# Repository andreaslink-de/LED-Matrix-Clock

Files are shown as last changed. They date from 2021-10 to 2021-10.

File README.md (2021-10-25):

# LED-Matrix-Clock

This [Link-Technologies.de](http://link-tech.de) project is about a simple ESP8266 driven clock.
Ok, another clock you ask, what is the purpose and what makes it special?

Well, as I am shortsighted and as I am sleeping without my glasses, I needed to have a clock on my nightstand, which is not too big, but big enough to be read without glasses in the night. It also has to be readable, but not too bright to disturb. It has to be exact and probably also slightly smart - and so I decided to create my own.

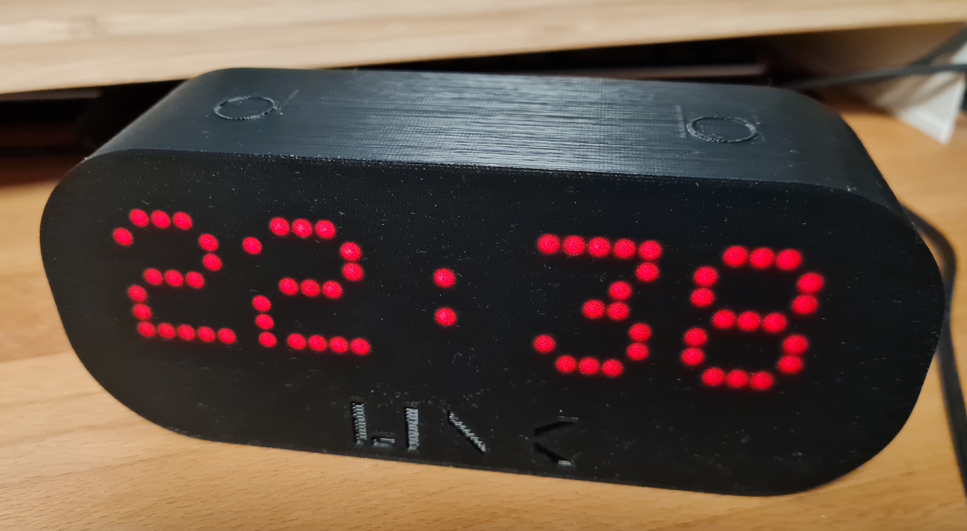
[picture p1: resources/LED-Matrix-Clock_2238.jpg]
LED-Matrix-Clock 22:38


This project describes a smart **LED-Matrix Clock**, which is readable without glasses in the night including some smart touch buttons and a temp/humidity sensor.

**This clock is able to...**

- show local time in big letters
- grab exact current time from internet
- change brightness
- be turned off aka fully dimmed (if being to bright)
- can be turned on again - permanently or only on demand
- connects to the (local) MQTT server
- has two touch buttons and posts the actions to the MQTT server aka broker
- subscribes to a topic of an outside temperature
- can show outside temperature on a touch
- has build in sensor to measure rooms local temperature and humidity (to provide via MQTT)
- can show sliding messages to transmit information (sent via MQTT)
- can show blinking alarm messages requiring attention (sent via MQTT)

## Technical Components

This clock is made of/implements...

- an ESP8266 (as WeMos D1 Mini) as core CPU
- four chained LED matrix (8x8) elements up to a visible 8x32 LED-Matrix
- a SHT21 for local temperature and humidity measurement
- two touch buttons (one dedicated and one multipurpose)
- Self designed black case (PLA) to dimm the brightness and hold it all together

## MQTT

After a successful start up and an active WiFi connection, the clock connects to the MQTT broker and sends some global health and info data.
The status is sent "retained" and can be used to determine, if the device is still there or has lost the connection to the broker (last will).

### Topics sent

Examples:

- 'zuhause/haus/schlafzimmer/iotdevice-clock/AndreasClockDevice/status': 'online'
- 'zuhause/haus/schlafzimmer/iotdevice-clock/AndreasClockDevice/clientid': 'IoTDevice-42AFFE'
- 'zuhause/haus/schlafzimmer/iotdevice-clock/AndreasClockDevice/devicename': 'iotdevice-clock'
- 'zuhause/haus/schlafzimmer/iotdevice-clock/AndreasClockDevice/version': '0.3'
- 'zuhause/haus/schlafzimmer/iotdevice-clock/AndreasClockDevice/ssid': ''IoT-Hausbus''
- 'zuhause/haus/schlafzimmer/iotdevice-clock/AndreasClockDevice/ip': '192.168.123.181'
- 'zuhause/haus/schlafzimmer/iotdevice-clock/AndreasClockDevice/mac': '50:02:91:42:AF:FE'
- 'zuhause/haus/schlafzimmer/iotdevice-clock/AndreasClockDevice/voltage': '3.089'
- 'zuhause/haus/schlafzimmer/iotdevice-clock/AndreasClockDevice/temperature': '20.1'
- 'zuhause/haus/schlafzimmer/iotdevice-clock/AndreasClockDevice/humidity': '41'

### Buttons

If the buttons are pressed, each pressing aka touching event is also sent via MQTT.
Some example events are:

- Button 1 clicked/touched:
  - 'zuhause/haus/schlafzimmer/iotdevice-clock/AndreasClockDevice/button1/touched': '1'
    - Typically to either show the outside temperature once
    - Or if display is turned off, show the time for some seconds
- Button 1 long pressed:
  - 'zuhause/haus/schlafzimmer/iotdevice-clock/AndreasClockDevice/button1/long': '1'
  - Turning LED Matrix off... good night!
  - If display is off, turn it on again
- Button 2 clicked/touched:
  - 'zuhause/haus/schlafzimmer/iotdevice-clock/AndreasClockDevice/button2/touched': '1'
  - Free event to implement/use in homeautomation system, e.g. turn on a night lamp
- Button 2 double clicked/touched:
  - 'zuhause/haus/schlafzimmer/iotdevice-clock/AndreasClockDevice/button2/doubletouched': '1'
  - Free event to implement/use in homeautomation system, e.g. turn on lights
- Button 2 long pressed:
  - 'zuhause/haus/schlafzimmer/iotdevice-clock/AndreasClockDevice/button2/long': '1'
  - Free event to implement/use in homeautomation system, e.g. open the blinds
  
 **Remind:**
 If Button 1 is pushed during boot, it will force the WiFi Manager to start up, so setup can be changed!

### Subscriptions and Commands

After reboot and successful connection to the MQTT broker the clock subscribes to the following topics (examples are according to initial setup via WiFi Manager).

**Subscribing to MQTT topics...**

- zuhause/garten/kinderhaus/aussen/temperatur
  - Last provided value is scrolled once when button 1 is pushed/touched
  - If no value is there, nothing happens
- zuhause/haus/schlafzimmer/iotdevice-clock/AndreasClockDevice/command/**reboot**
  - If value is 1, the clock is rebooted
- zuhause/haus/schlafzimmer/iotdevice-clock/AndreasClockDevice/command/**led**
  - If value is 1, the LED on the ESP8266 is turned on
  - If value is 0, the LED on the ESP8266 is turned off
  - If value is 2, the LED on the ESP8266 is toggled
  - Info: This function was implemented for testing and development purposes and does not give any real value.
- zuhause/haus/schlafzimmer/iotdevice-clock/AndreasClockDevice/command/**deletewificonfig**
  - Deletes the WiFi config and forces the WiFi Manager to kick in with the reboot
  - Triggers a reboot
- zuhause/haus/schlafzimmer/iotdevice-clock/AndreasClockDevice/command/**factoryreset**
  - Well, all is gone as the SPIFFS is fully wiped
- zuhause/haus/schlafzimmer/iotdevice-clock/AndreasClockDevice/command/**showmessage**
  - Scrolls the given text two times over the matrix
  - Can be used to transmit urgent short messages, e.g. by the home automation system
- zuhause/haus/schlafzimmer/iotdevice-clock/AndreasClockDevice/command/**showtext**
  - Shows a text with max. 5 chars flashing on highest brightness
  - Message is blinking a few times and then disappears again
  - Can be used to send e.g. 'ALARM' or any other <=5 char word
- zuhause/haus/schlafzimmer/iotdevice-clock/AndreasClockDevice/command/**setledmatrixstatus**
  - If value is 1, the LED matrix is turned on
  - If value is 0, the LED matrix is turned off
  - It can be used to automatically turn a display on and off triggered by a home automation system, such it is off in the nights (if someone is sensitive) or if no one is a home
  - Value is also set/influenced/changed when holding button 1
- zuhause/haus/schlafzimmer/iotdevice-clock/AndreasClockDevice/command/**setledmatrixbrightness**
  - Sets the brightness between 1 and 15

## Case

The case is 3D printed and the STLs are also available. Please find the main case [here](./case/Clock-MainCase_LED-Matrix-ESP8266_v1.stl). A first version of the back lid is added [here](./case/Clock-BackLid_LED-Matrix-ESP8266_v1.stl) as well, but I am still working on this one (as I forgot a holder and hole for the SHT21 sensor \*facepalm\*).

I have printed my case with common cheap black PLA on an Prusa MK3S and it is the first print shown on the pictures here. My print time was at around 5h to 6h.
The back lid is screwed on the case by melting some M3 nuts into the holes before. I like things screwed and no clips, which can break :-).

**Remind:** I recommand using plain _black PLA_ (or maybe PETG) to get the best effect of the LED matrix display shining though the front. I tried with white, but this was too bright for me.

### Outstanding todos

- Optimze the clips at the touch sensors --> Make them slightly thinner
- Slightly widen the USB Port hole
- Upload finished back lid and add corresponding pictures
- Add a sensor hole to the back lid

----------

## Pictures

See following some more pictures:

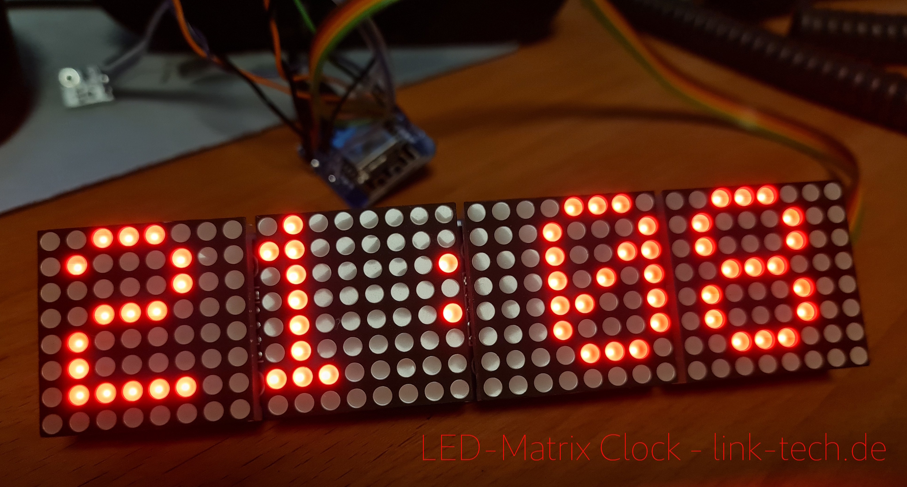
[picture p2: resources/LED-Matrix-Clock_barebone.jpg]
LED-Matrix-Clock 8x32 LED-Matrix 8x32


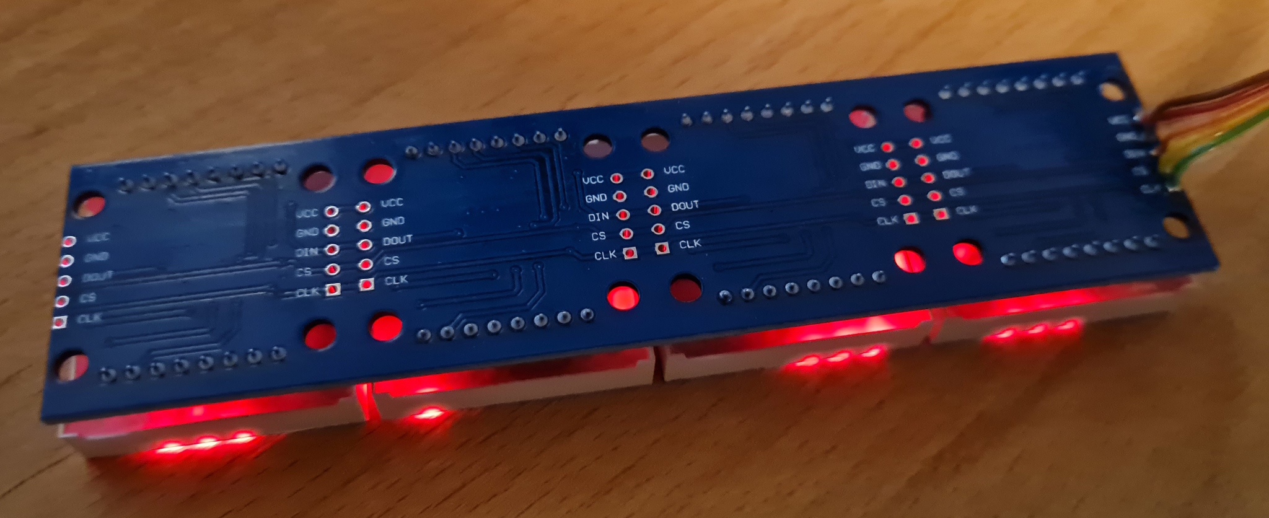
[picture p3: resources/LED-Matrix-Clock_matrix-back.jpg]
LED-Matrix-Clock LED-Matrix Back


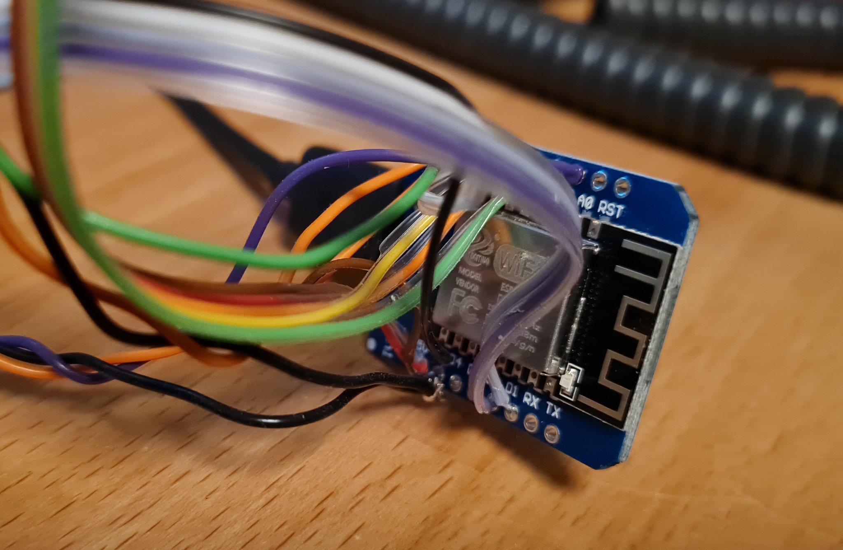
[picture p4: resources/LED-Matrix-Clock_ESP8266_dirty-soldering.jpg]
LED-Matrix-Clock soldered ES8266 LED-Matrix ESP8266 WeMos D1 Mini


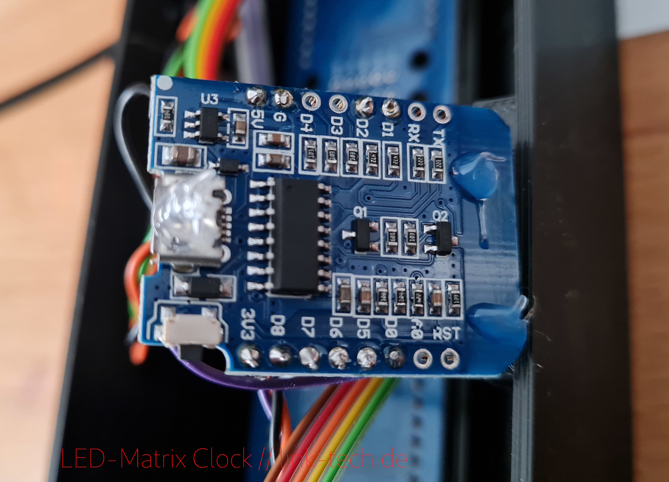
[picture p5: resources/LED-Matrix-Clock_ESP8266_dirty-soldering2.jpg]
LED-Matrix-Clock soldered ES8266 LED-Matrix ESP8266 WeMos D1 Mini


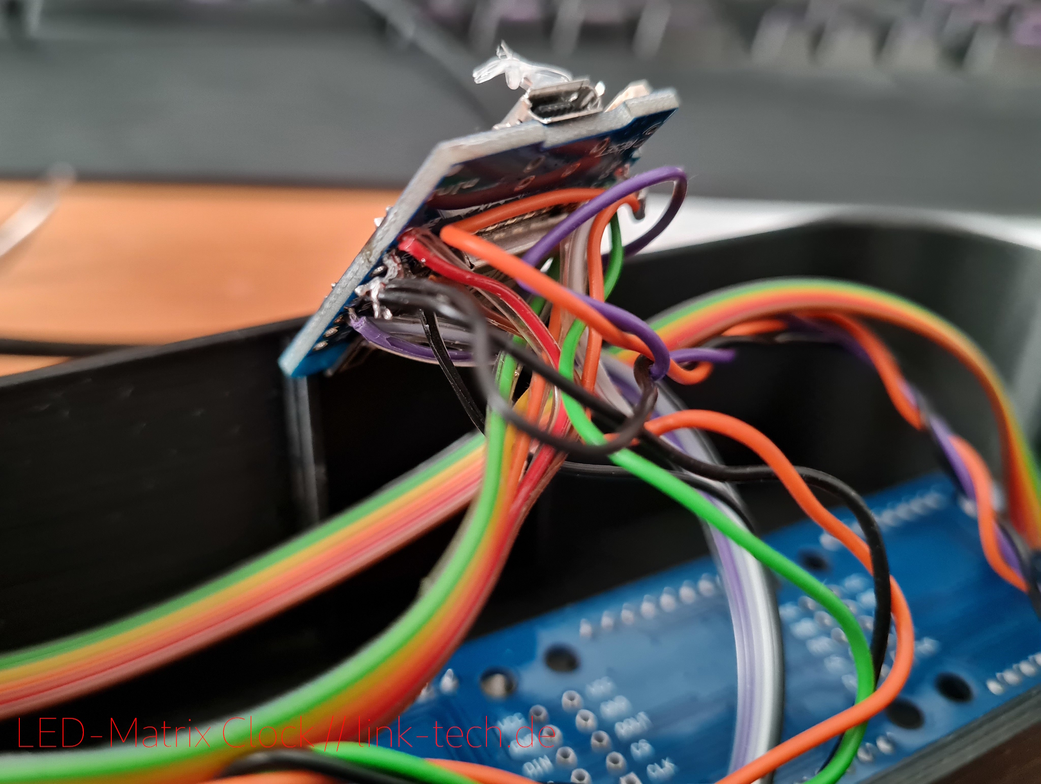
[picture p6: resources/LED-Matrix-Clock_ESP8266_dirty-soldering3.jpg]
LED-Matrix-Clock soldered ES8266 LED-Matrix ESP8266 WeMos D1 Mini


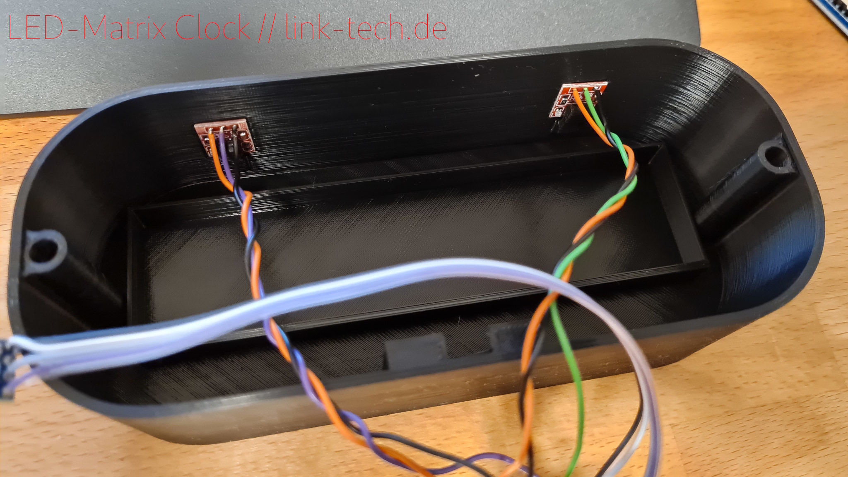
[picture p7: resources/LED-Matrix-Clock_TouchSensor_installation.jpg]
LED-Matrix-Clock Touch Sensor LED-Matrix Clock Touch Sensor Installation


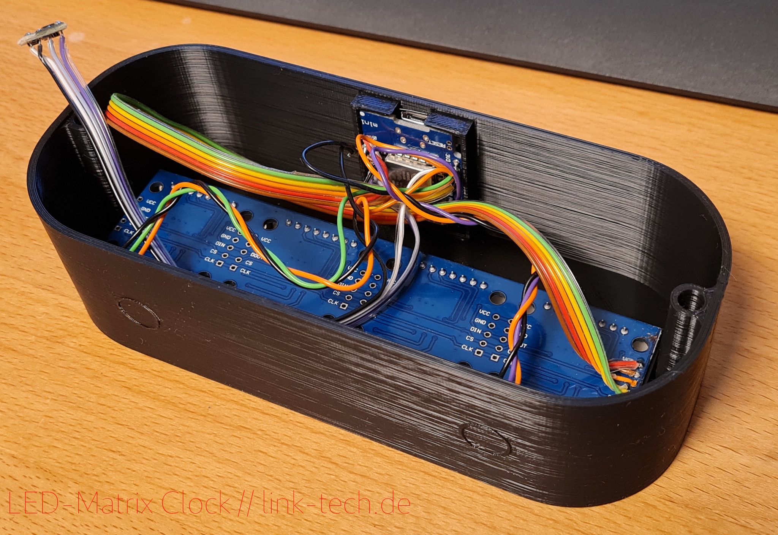
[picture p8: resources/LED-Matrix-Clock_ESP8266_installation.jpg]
LED-Matrix-Clock ESP8266 LED-Matrix Clock ESP8266 Installation


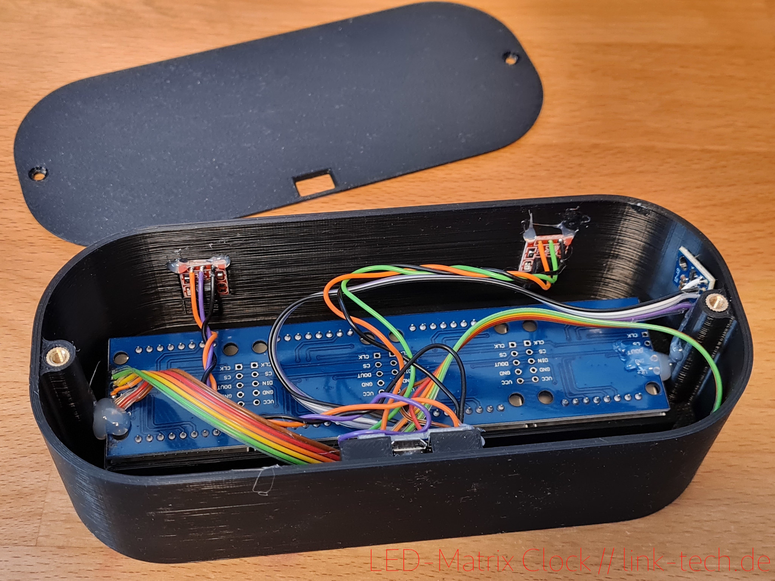
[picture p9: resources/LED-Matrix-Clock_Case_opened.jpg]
LED-Matrix-Clock Display, Touch Sensors, nuts LED-Matrix Clock Display and Touch Sensor installed, all hot glue fixed, M3 screw nuts


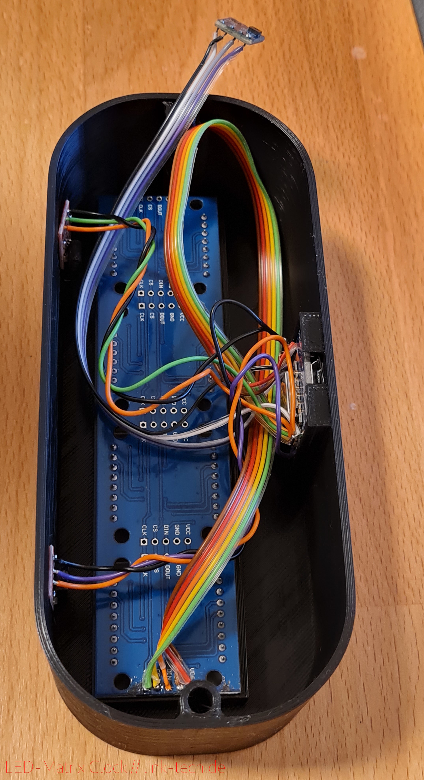
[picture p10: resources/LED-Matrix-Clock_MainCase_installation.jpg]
LED-Matrix-Clock Cableing LED-Matrix Clock Cableing


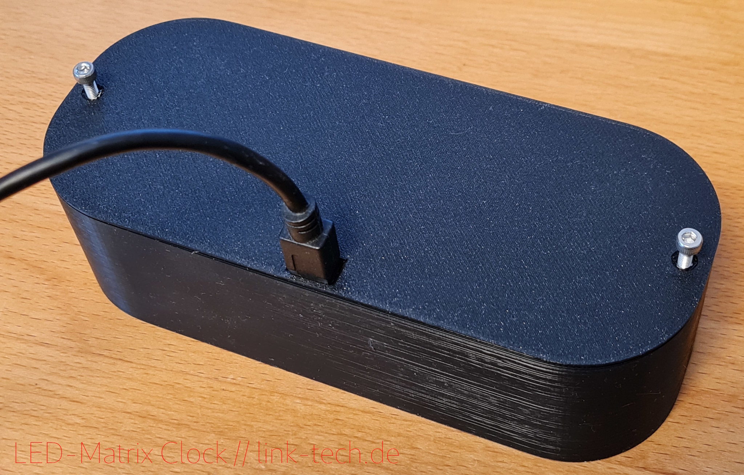
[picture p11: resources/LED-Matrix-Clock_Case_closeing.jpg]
LED-Matrix-Clock Closing LED-Matrix Clock Case M3 Screws Closing


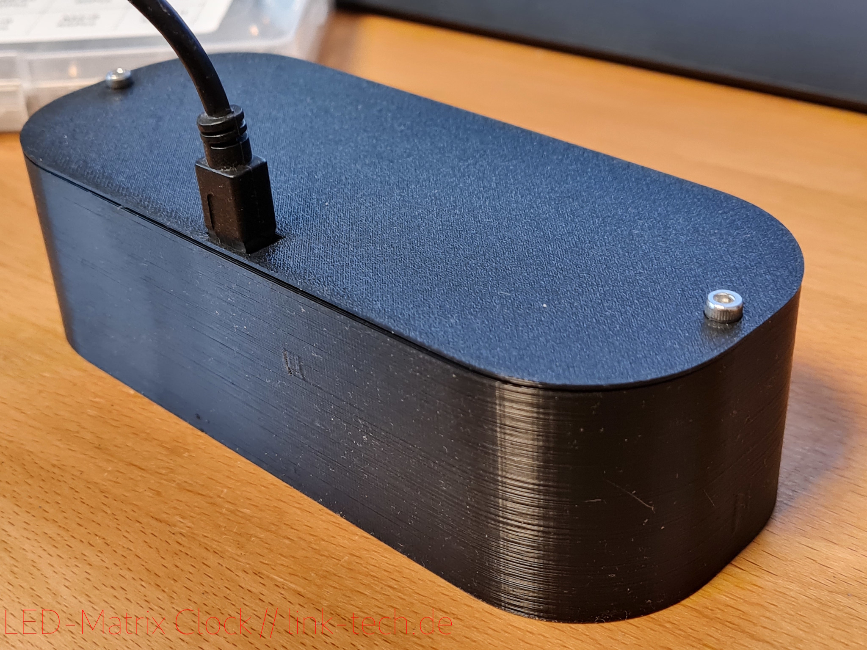
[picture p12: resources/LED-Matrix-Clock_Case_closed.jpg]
LED-Matrix-Clock Closed LED-Matrix Clock Case Closed


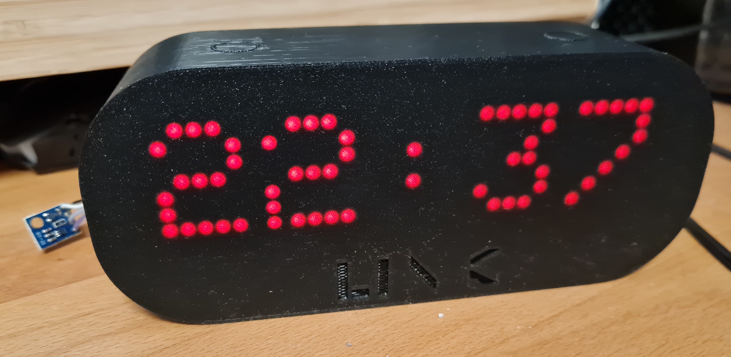
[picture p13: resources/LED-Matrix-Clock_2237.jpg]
LED-Matrix-Clock 22:37


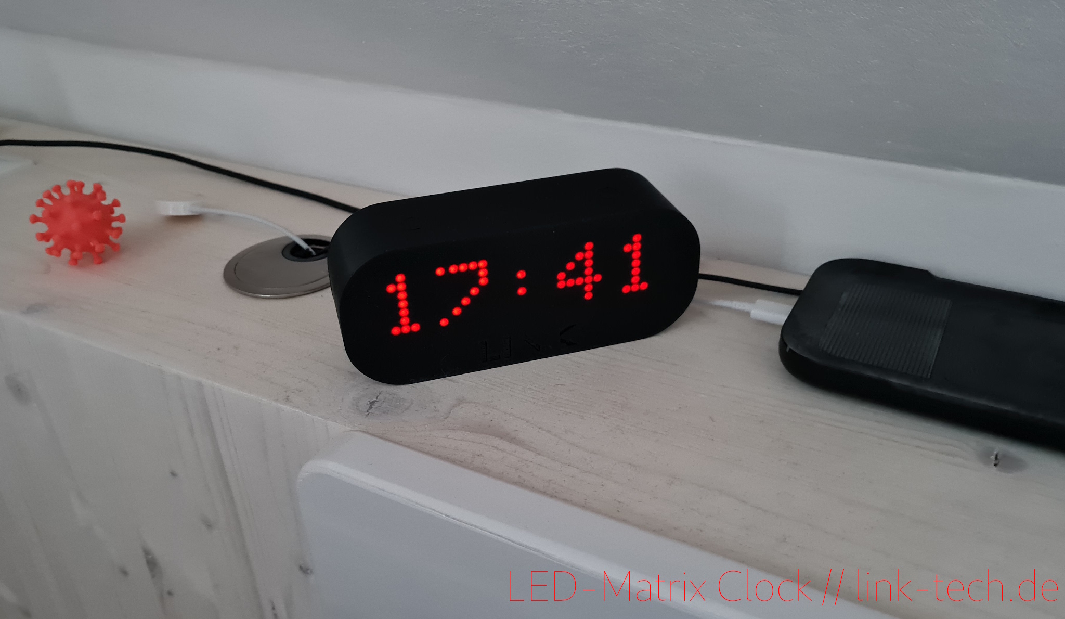
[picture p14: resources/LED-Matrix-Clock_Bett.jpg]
LED-Matrix-Clock Bett 17:41 LED-Matrix-Clock 17:41


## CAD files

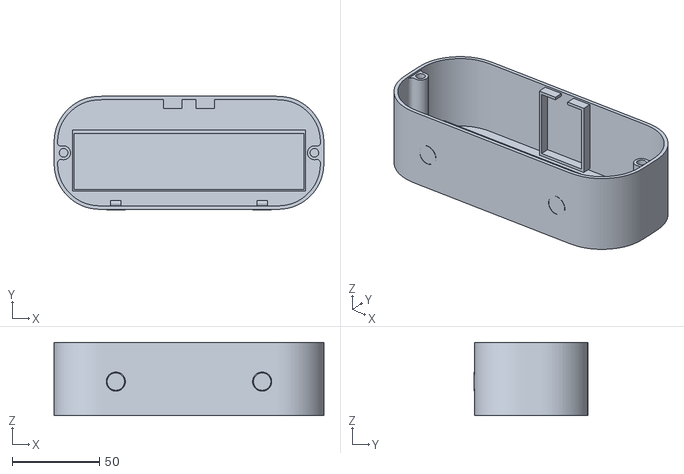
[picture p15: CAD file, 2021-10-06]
case/Clock-MainCase_LED-Matrix-ESP8266_v1.stl
155.0 x 65.2 x 42.0

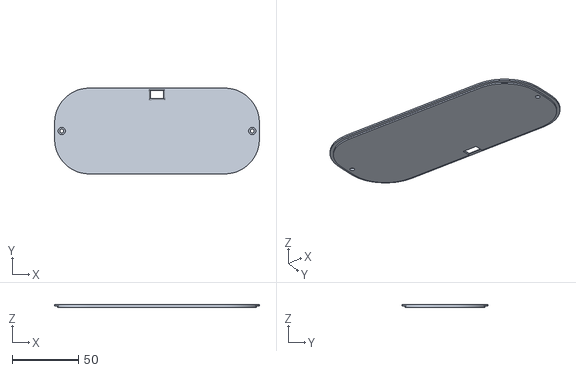
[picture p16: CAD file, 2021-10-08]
case/Clock-BackLid_LED-Matrix-ESP8266_v1.stl
155.0 x 65.0 x 2.00

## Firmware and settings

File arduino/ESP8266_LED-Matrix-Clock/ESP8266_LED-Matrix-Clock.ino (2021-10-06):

/*------------------------------------------------------------------------------------
 * ESP8266 - LED-Matrix Clock
 * 
 * Author:  Dipl.-Inform. (FH) Andreas Link
 * Date:    21.07.2021 Harrislee, Germany
 * Web:     Link-Technologies.de
 * License: GNU General Public License, Version 3
 * 
 * Usage:
 *   Boots, connects to WiFi or asks for WiFi access, connects to internet to get time from
 *   NTP server. Connects to MQTT server to send events if buttons are pushed/touched and to 
 *   subscribe to outside temperature.
 *   Firmwareupdates via OTA are possbile.
 *
 * Remind: 
 *   Consider to preset your "config.h" with relevant passswords for accessing the 
 *   WiFi Manager on first boot.
 ------------------------------------------------------------------------------------*/


#define DEBUG_OUTPUT      // Uncomment to enable serial IO debug messages
#define USE_MQTT          // Comment to deactivate MQTT (which is biggest part)
#define USE_NTP_TIME      // Comment to deactivate use of internet time to get correct local date and time
#define USE_SHT21         // Comment to deactivate use of SHT21 Temperature and Humidity sensor
//#define USE_BH1750        // Comment to deactivate BH1750 brightness integration <-- NOT YET FULLY IMPLEMENTED!



/* *********************************************** <<< DEBUG >>> ****************************************************/
////////////////////////
// Debug Serial Magic //
////////////////////////
#ifdef DEBUG_OUTPUT
  #define DEBUG(input)   { Serial.print(input); }
  #define DEBUGln(input) { Serial.println(input); }
#else
  #define DEBUG(input) ;
  #define DEBUGln(input) ;
#endif

/* *********************************************** >>> DEBUG <<< ****************************************************/


#define FW_VERSION "0.3"
#include "config.h"

#define MQTT_MAX_PACKET_SIZE 1024 // Remind: If you mess with this value and go too low, the code throws weird exceptions
#define BUTTON1   15              // GPIO15 aka D8
#define BUTTON2   16              // GPIO16 aka D0


#include <FS.h>                   // This needs to be first, or it all crashes and burns...
#include <ESP8266WiFi.h>          // https://github.com/esp8266/Arduino
#include <ESP8266mDNS.h>
#include <WiFiUdp.h>
#include <ArduinoOTA.h>
#include <DNSServer.h>
#include <ESP8266WebServer.h>
#include <WiFiManager.h>          // https://github.com/tzapu/WiFiManager
#include <ArduinoJson.h>          // https://github.com/bblanchon/ArduinoJson

#include <Adafruit_GFX.h>         // https://github.com/adafruit/Adafruit-GFX-Library
#include <Max72xxPanel.h>         // https://github.com/markruys/arduino-Max72xxPanel

#include <AceButton.h>
using namespace ace_button;

#ifdef USE_MQTT
  #include <PubSubClient.h>
#endif

#ifdef USE_NTP_TIME
  #include <NTPClient.h>
  #include <WiFiUdp.h>
  #include "RTClib.h"             //Makes DateTime calculations possible first
#endif

#ifdef USE_SHT21
  #include "SparkFunHTU21D.h"     // https://github.com/sparkfun/SparkFun_HTU21D_Breakout_Arduino_Library
#endif

#ifdef USE_BH1750
  #include <BH1750.h>             // https://github.com/claws/BH1750
#endif


//Read power via ADC
ADC_MODE(ADC_VCC);

/* *********************************************** <<< Config >>> ****************************************************/
// ----------------------------------------- MQTT ------------------------------------------ //
#ifdef USE_MQTT
  //MQTT-Topic/Data Max-Length
  #define MAX_TOPIC_LENGTH 100
  #define MAX_DATA_LENGTH 100
  
  //MQTT-Setup
  char mqttBaseTopic[MAX_TOPIC_LENGTH];
  char mqttButton1Topic[MAX_TOPIC_LENGTH];
  char mqttButton2Topic[MAX_TOPIC_LENGTH];
  char mqttLightTopic[MAX_TOPIC_LENGTH];
  char mqttTempTopic[MAX_TOPIC_LENGTH];
  char mqttHumidityTopic[MAX_TOPIC_LENGTH];
  
  //Dedicated subscribe topics
  //const char* mqttSubTopicOutTemp = "zuhause/garten/kinderhaus/aussen/temperatur";
    //const char* q = "abc";
    //const char*& c = q;
  
  const char* &mqttSubTopicOutTemp = outsideTemperatureMQTTtopic;
  const char* mqttSubTopicDate    = "system/date";
  const char* mqttSubTopicTime    = "system/time";
#endif


// ------------------------------------ WiFi-Manager --------------------------------------- //

//WiFiManager Vars:
bool shouldSaveConfigToFlash = false;  //Flag for saving data

//define your default values here, if there are different values in config.json, they are overwritten.
//length should be max size + 1
char flashIoTdeviceName[50];
char flashMQTTserver[40];
char flashMQTTport[6];
char flashMQTTbaseTopic[50];
char flashMQTTdeviceTopic[50];

//Vars:
float gESPVCC = 0.0;
String gIP = "not connected";
String gWiFiStatus = "not connected";

String curDate = "";
String curTime = "";
String gFormerTimeNow = "";
uint8_t gShowTimeOnce = false;

String gMacAdr = "00:00:00:00:00:00";
char gIdentifierAry[7];
String gIdentifier = "000000";
String gSSID = "";
uint8_t mqttConnectFailCounter = 0;
unsigned long lastDoSomethingEvent = 0;
unsigned long lastReconnectAttempt = 0;
boolean gForceWiFiManager = false;

//LED-Matrix ON/OFF status
uint8_t gLEDmatrixTurnedOn = true;
uint8_t gLEDmatrixWasTurnedOffBefore = false;

//Receive a message, and show it on the display vars
String gMessage = "";
uint8_t gNewMessageToShow = false;

//Blink Short Urgent Text vars
unsigned long lastShowTextTimeSlot = 0;
String gShortText = "";
uint8_t gNewTextToShow = false;
uint8_t gCurrentlyShowingText = false;
uint8_t gTextBlinkToggle = false;
unsigned long lastShowTextBlinkTimeSlot = 0;

//Show outside temp on display
String gOutsideTempStr = "N/A"; //Max char size: -00.00
unsigned long lastShowOutTempTimeSlot = 0;
uint8_t gNewOutTempToShow = false;
uint8_t gCurrentlyShowingOutsideTemp = false;


#ifdef USE_SHT21
  float gTempFl = 0.0;
  float gHumidityFl = 0;
  String gTempStr = "N/A";
  String gHumidityStr = "N/A";
  unsigned long lastTempHumiditySent = 0;

  //Defining SHT21 via SparkFun-Lib
  HTU21D sht21; // I²C-Address: 0x40
#endif

#ifdef USE_BH1750
  //Define BH1750 lightmeter
  BH1750 lightMeter(0x23);  // I²C-Address: 0x23

  unsigned long lastBrightnessSent = 0;
  uint16_t gLux = 0;
  String gLuxStr = "N/A";
#endif

#ifdef USE_NTP_TIME  
  WiFiUDP ntpUDP;

  // You can specify the time server pool and the offset (in seconds, can be
  // changed later with setTimeOffset() ). Additionaly you can specify the
  // update interval (in milliseconds, can be changed using setUpdateInterval() ).
  NTPClient timeClient(ntpUDP, "europe.pool.ntp.org", 3600, 60000);

  long gTargetDateLong = 0;
  boolean gDisplaySleeping = false;
#endif



//Define an ESP-WiFi-Client for MQTT-connection
WiFiClient espClient;

#ifdef USE_MQTT
  PubSubClient mqttClient(espClient);
#endif



/* *********************************************** Setup ****************************************************/
void setup()  
{
  //Basic assign of vars from config.h
  strncpy(flashIoTdeviceName, myFlashIoTdeviceName, 50);
  strncpy(flashMQTTserver, myFlashMQTTserver, 40);
  strncpy(flashMQTTport, myFlashMQTTport, 6);
  strncpy(flashMQTTbaseTopic, myFlashMQTTbaseTopic, 50);
  strncpy(flashMQTTdeviceTopic, myFlashMQTTdeviceTopic, 50);

  
  Serial.begin(115200);
  delay(100);

  DEBUGln();
  DEBUGln(F("------------------------------------------------------------"));
  DEBUG  (F("  Andreas Smart Clock v"));
  DEBUGln(FW_VERSION);
  DEBUG  (F("  ESP8266 Chip-ID: "));
  DEBUGln(ESP.getChipId());
  DEBUG  (F("  MAC Address: "));
  DEBUGln(WiFi.macAddress());
  DEBUGln();
  DEBUG  (F("  Sketch size (kB): "));
  DEBUG  (ESP.getSketchSize()/1000.0);
  DEBUG  (F(" ("));
  DEBUG  (ESP.getSketchSize());
  DEBUGln(F(" Byte)"));
  DEBUG  (F("  Free space (kB): "));
  DEBUG  (ESP.getFreeSketchSpace()/1000.0);
  DEBUG  (F(" ("));
  DEBUG  (ESP.getFreeSketchSpace());
  DEBUGln(F(" Byte)"));
  DEBUG  (F("  Free Mem/Heap (kB): "));
  DEBUG  (ESP.getFreeHeap()/1000.0);
  DEBUG  (F(" ("));
  DEBUG  (ESP.getFreeHeap());
  DEBUGln(F(" Byte)"));
  DEBUGln();
  DEBUGln(F("           Dipl.-Inform. (FH) Andreas Link"));  
  DEBUGln(F("               Release Build 07.2021"));
  DEBUGln(F("                www.andreaslink.de"));
  DEBUGln(F("             www.link-technologies.de"));
  DEBUGln(F("------------------------------------------------------------"));
  DEBUGln();

  // Prepare Debug-LED GPIO2 (TX1) for testing/measuring (IF NO SERIAL2 IS USED!)
  pinMode(LED_BUILTIN, OUTPUT); // Initialize digital pin LED_BUILTIN as an output.
  digitalWrite(LED_BUILTIN, HIGH); // Turn the LED off (HIGH = off, LOW = on)
  //pinMode(2, OUTPUT); // LED vorbereiten
  //digitalWrite(2, 1); // Turn LED off
  
  ledDoubleFlash();

  //Set unique MAC oriented device identifier
  gIdentifier = getUniqueDeviceIdentifier(); //Predefine unique identifier (from MAC)

  //Setup attached buttons
  initButtons();

  // Read current voltage
  gESPVCC = ESP.getVcc()/1000.0;
  DEBUG(F("Spannung: "));
  DEBUG(gESPVCC);
  DEBUGln(F(" V"));

  //Init LED Matrix Display
  initLEDmatrix();


#ifdef USE_NTP_TIME
  timeClient.begin();
#endif

#ifdef USE_SHT21
  //Initiate I²C
  Serial.println("Init I²C for e.g. SHT21 and/or BH1750...");
  Wire.begin();

  //Init SHT21
  DEBUG(F("Init/Prepare SHT21 Temp/Humidity sensor and read first values..."));
  sht21.begin();  // default: sda=4, scl=5
  updateSHT21();
  DEBUGln(F("done."));

  //Print formerly read temp/humidity
  DEBUGln();
  DEBUGln(F("Temperature and humidity from SHT21 sensor:"))
  DEBUG(F("  Temperature: "));
  DEBUG(gTempStr);
  DEBUGln(F(" C"));
  DEBUG(F("  Humidity: "));
  DEBUG(gHumidityStr);
  DEBUG(F(" %"));
  DEBUGln();
#endif

#ifdef USE_BH1750
  //Initiate I²C
  DEBUG(F("Init I²C + BH1750... "));
  Wire.begin();

  // Init BH1750
  lightMeter.begin(BH1750_CONTINUOUS_HIGH_RES_MODE_2);  // Possible modes: BH1750_CONTINUOUS_LOW_RES_MODE, BH1750_CONTINUOUS_HIGH_RES_MODE (default), BH1750_CONTINUOUS_HIGH_RES_MODE_2
                                                        //                 BH1750_ONE_TIME_LOW_RES_MODE,   BH1750_ONE_TIME_HIGH_RES_MODE,             BH1750_ONE_TIME_HIGH_RES_MODE_2  
  DEBUGln(F("done."));

  //Update current brightness value
  updateLight();
  DEBUGln();
  DEBUG(F(" Measured Light: "));
  DEBUG(gLuxStr);
  DEBUGln(F(" lux"));
#endif


  //Read Data from SPIFFS to prepare for WiFiManager
  DEBUGln(F("Reading from SPIFFS..."));
  if (readDataFromSPIFFS())
  {
    DEBUGln(F("Reading from SPIFFS was successful."));
  } else {
    DEBUGln(F("Reading from SPIFFS FAILED!"));
  }
  DEBUGln();

  // Initial Wifi mode setup and connection to WiFi:
  //Start WiFiManager or connect to WiFi
  DEBUGln(F("Starting WiFiManager and trying to connect to WiFi..."));
  scrollMessage("Connecting...");
  centerPrint("WiFi?");
  if (InitWiFiManager())
  {
    DEBUGln(F("WiFi successfully connected via WiFi-Manager!"));    
  } else {
    DEBUGln(F("WiFi connection via WiFi-Manager FAILED!"));
  }

  //Init protected OTA Update
  initOTA();

#ifdef USE_MQTT
  // Puzzle finale strings together to connect to mqtt server based on saved/entered input
  prepareMQTTparams();
  
  //Init MQTT broker details for MQTT broker and setup callback
  DEBUG(F("Init/Prepare MQTT-server: "));
  DEBUG(flashMQTTserver);
  DEBUG(F(":"));
  DEBUGln(flashMQTTport);
  mqttClient.setServer(flashMQTTserver, atoi(flashMQTTport));
  //mqttClient.setServer((const char *)"192.168.0.253", atoi(flashMQTTport));
  //mqttClient.setServer(mqttServer, atoi(flashMQTTport));
  //mqttClient.setServer(mqttServer, 1883);
  mqttClient.setCallback(mqttCallback);
#endif


#ifdef USE_NTP_TIME
  //Force Summertime --> Needs to be improved via code
  //setSummertime(true);
#endif  

  DEBUGln();
  DEBUGln(F("-- Initial setup is done --"));
  DEBUGln();
}




/* *********************************************** Loop ****************************************************/

void loop()
{
  //Check the button states
  checkButtonStates();
  
  unsigned long now = millis();

  //Clear all time slot counters, if millis reached the end of unsigned long some point in time
  if (now < lastDoSomethingEvent)
    lastDoSomethingEvent = 0;

  if (now < lastShowTextTimeSlot)
    lastShowTextTimeSlot = 0;

  if (now < lastShowTextBlinkTimeSlot)
    lastShowTextBlinkTimeSlot = 0;    

  if (now < lastReconnectAttempt)
    lastReconnectAttempt = 0;

  #ifdef USE_SHT21
  if (now < lastTempHumiditySent)
    lastTempHumiditySent = 0;
  #endif

  #ifdef USE_BH1750
  if (now < lastBrightnessSent)
    lastBrightnessSent = 0;
  #endif
    
  
  //WiFi is still up:
  if (WiFi.status() != WL_CONNECTED)
  {
    DEBUG(timestamp());
    DEBUGln(F(" ERROR: WiFi lost! Rebooting..."));
    ESP.reset();
  }

  //Handle OTA Update progress
  ArduinoOTA.handle();

  #ifdef USE_NTP_TIME
    timeClient.update();
  #endif

 
  #ifdef USE_MQTT
  // Handle MQTT messages, if connected
  if (!mqttClient.connected())
  {    
    if (now - lastReconnectAttempt > 5000) 
    {
      lastReconnectAttempt = now;
      
      // Attempt to reconnect
      if (mqttReconnect()) 
      {
        lastReconnectAttempt = 0;
        mqttClient.loop();
      }
      ledFlash();
      delay(200);
      ledFlash();
    }
  } else {
    // MQTT-Client is connected:
    mqttClient.loop();
      
    #ifdef USE_BH1750
      //Send brightness every ~30 seconds
      if (now - lastBrightnessSent > 30000) 
      {
        lastBrightnessSent = now;
  
        DEBUGln();
        DEBUGln(F("Reading light from BH1750 sensor..."));
        updateLight();
        DEBUG(F("  Measured Light: "));
        DEBUG(gLuxStr);
        DEBUGln(F(" lux"));
                
        sendMQTTmsg(mqttLightTopic, gLuxStr, false);
      }      
    #endif


    // Shall I show the received outside temp?
    if (gNewOutTempToShow)
    {
      gNewOutTempToShow = false;
      
      String temp = gOutsideTempStr + " " + (char)247 + "C";  //Prints: "-12.34 °C"
      scrollMessage(temp,35);      
      gFormerTimeNow = "";

      /*
      //Starting new timeslot
      if (!gCurrentlyShowingOutsideTemp)
      {
        lastShowOutTempTimeSlot = now;
        gCurrentlyShowingOutsideTemp = true;
        setLEDmatrixBrightness(5);
      }
  
      //As long as we are in the time slot
      if (now - lastShowOutTempTimeSlot < 3000)
      {
        centerPrint(gOutsideTempStr);
      } else {
        gCurrentlyShowingOutsideTemp = false;
        gNewOutTempToShow = false;
        gFormerTimeNow = "";
        setLEDmatrixBrightness(1);
      }
      */
    }


    #ifdef USE_SHT21
      if (now - lastTempHumiditySent > 60000)
      {
        lastTempHumiditySent = now;
  
        DEBUGln();
        DEBUG(timestamp());
        DEBUGln(F("Reading temperature and humidity from SHT21 sensor..."));
        updateSHT21();
        DEBUG(F("  Measured Temperature: "));
        DEBUG(gTempStr);
        DEBUG(F(" "));
        //DEBUG((char)247);
        DEBUGln(F("C"));
  
        DEBUG(F("  Measured Humidity: "));      
        DEBUG(gHumidityStr);
        DEBUGln(F(" %"));
        DEBUGln();
        
        //Send values via MQTT
        sendMQTTmsg(mqttTempTopic, gTempStr, false);
        sendMQTTmsg(mqttHumidityTopic, gHumidityStr, false);
      }
    #endif
    
    
  } // End of MQTT connected
  #else
    // If compiled without MQTT support, then show date on demand
    // Shall I show the date?
    if (gNewOutTempToShow)
    {
      gNewOutTempToShow = false;

      //Calc date:
      unsigned long unixNow = getNowUnixTimestamp();
      DateTime rightNow(unixNow);

      String dateToday = "";      
      if (rightNow.day() < 10)
      {
        dateToday = "0" + (String)rightNow.day();
      } else {
        dateToday = (String)rightNow.day();
      }
      dateToday += ".";
      
      if (rightNow.month() < 10)
      {
        dateToday += "0" + (String)rightNow.month();
      } else {
        dateToday += (String)rightNow.month();
      }
      dateToday += "." + (String)rightNow.year();

      DEBUG("Showing the date: ")
      DEBUGln(dateToday);
      
      scrollMessage(dateToday,35);      
      gFormerTimeNow = "";    
    }  
  #endif


  // Is there a message to show in the message buffer?
  if (gNewMessageToShow)
  {
    //Show message once and reset trigger
    gNewMessageToShow = false;
    scrollMessage(gMessage);
    scrollMessage(gMessage);    

    //Just to be sure, if this scrolling message interrupted a short text display to kick in again
    if (gNewTextToShow)
    {
      now = millis();
      lastShowTextTimeSlot = now;
      lastDoSomethingEvent = now;
    } else {
      gFormerTimeNow = "";
    }
  }


  // Is there a short text to show in the message buffer? If yes, show it for some seconds and then reset the trigger
  if (gNewTextToShow)
  {
    //Starting new timeslot
    if (!gCurrentlyShowingText)
    {
      lastShowTextTimeSlot = now;
      gCurrentlyShowingText = true;
      setLEDmatrixBrightness(10);

      //If the display is off, turn it on
      if (!gLEDmatrixTurnedOn)
      {
        //Remind old status
        gLEDmatrixWasTurnedOffBefore = true;
        
        //Turn display on:
        setLEDmatrixOnOffStatus(true);
      }        
    }

    //As long as we are in the time slot
    if (now - lastShowTextTimeSlot < 3000)
    {
      // Toggle blinker
      if (now - lastShowTextBlinkTimeSlot > 250)
      {
        gTextBlinkToggle = !gTextBlinkToggle;
        lastShowTextBlinkTimeSlot = now;
      }

      //Show text depending on toggle state
      if (gTextBlinkToggle)
      {
        centerPrint(gShortText);
      } else {
        clearLEDmatrix();
      }
    } else {
      gCurrentlyShowingText = false;
      gNewTextToShow = false;      
      gFormerTimeNow = "";
      setLEDmatrixBrightness(1);

      if (gLEDmatrixWasTurnedOffBefore)
      {
        //Turn display off again and reset the reminder
        setLEDmatrixOnOffStatus(false);
        gLEDmatrixWasTurnedOffBefore = false;
      }
    }
  }
  
   
  
  
  //Check, if time slot event is reached and usually show current time here:
  if (now - lastDoSomethingEvent > 500)
  {
    lastDoSomethingEvent = now;

    //Evaluate if we are in summer or winter time
    doWeHaveSummerOrWinterTime();

    //Get current time from NTP
    String timeNow = getNowSimpleFormatedTime();
    
    /*
    //Calculate the date values and time span
    unsigned long unixNow = getNowUnixTimestamp();
    DateTime rightNow(unixNow);
    printDateOnSerial("Current DateTime: ", rightNow);
    */

    if ((gFormerTimeNow != timeNow && gLEDmatrixTurnedOn) || gShowTimeOnce)
    {
      //Forceing to show the time briefly, when display is turned off
      if (gShowTimeOnce)
      {
        setLEDmatrixOnOffStatus(true);
        setLEDmatrixBrightness(0);
      }

      //Print the time centered
      centerPrint(timeNow);
      gFormerTimeNow = timeNow;

      if (gShowTimeOnce)
      {
        delay(1500);        
        setLEDmatrixOnOffStatus(false);
        setLEDmatrixBrightness(1);
        gShowTimeOnce = false;
      }
    }
  } 
}

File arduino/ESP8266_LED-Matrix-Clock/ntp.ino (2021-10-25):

#ifdef USE_NTP_TIME

unsigned long gDeltaUnixTimestamp = 0;


unsigned long getNowUnixTimestamp()
{
  return timeClient.getEpochTime();
}


int getNowWeekday() //0 is Sunday
{
  return timeClient.getDay();
}

int getNowHours()
{
  return timeClient.getHours();
}

int getNowMinutes()
{
  return timeClient.getMinutes();
}

int getNowSeconds()
{
  return timeClient.getSeconds();
}

String getNowFormatedTime()  //21:42:23
{
  return timeClient.getFormattedTime();
}


String getNowSimpleFormatedTime()  //21:42
{
  if (timeClient.getMinutes() < 10)
  {
    return (String)timeClient.getHours() + ":0" + (String)timeClient.getMinutes();
  } else {
    return (String)timeClient.getHours() + ":" + (String)timeClient.getMinutes();
  }
}


long calculateDeltaSeconds(unsigned long pTargetUnixTimestamp)
{
  //Always takes now as reference
  long delta = pTargetUnixTimestamp - getNowUnixTimestamp();

  if (delta <= 0)
  {
    //Date is in the past, so force to 0
    delta = 0;
  }
  
  return delta;
}


boolean timeToSleep(const DateTime &dt)
{
  return (dt.hour() >= 1 && dt.hour() < 6);
  //return (dt.hour() >= 22 && dt.minute() == 41);
}


void setSummertime(boolean pSummer)
{
  if (pSummer)
  {
    timeClient.setTimeOffset(7200);
    //DEBUGln("Summertime (+2h)");
  } else {
    timeClient.setTimeOffset(3600);
    //DEBUGln("Wintertime (+1h)");
  }
}


void doWeHaveSummerOrWinterTime()
{
  /*
   * The EU of course has a guideline on it that determines the daylight saving time to start on the last Sunday 
   * of March and to end on the last Sunday of October. In the EU the hour to switch is at 01:00 UTC. In practice 
   * UTC is equal to GMT (Greenwich Mean Time).
  */

  DateTime rightNow(getNowUnixTimestamp());
  
  int dow = getNowWeekday();
  int mon = rightNow.month();
  int d = rightNow.day();
  int h = rightNow.hour();

  // Debug:
  //dow = 3;  // 1 (Mo.)
  //mon = 10; // 10
  //d = 28;   // 25
  //h = 14;   // 1

  // As October has 31 days, we know that the last Sunday (dow=0) will always fall from the 25th to the 31st.
  // Outside this time it is for sure wintertime.
  if (mon >= 11 || mon < 3) 
  {
    setSummertime(false);
    return;
  } else if (mon == 10 && d < 26)
  {
    setSummertime(true);
    return;
  } else if (dow == 0 && mon == 10 && d >= 26 && h >= 3)
  {
    setSummertime(false);
    return;
  } else if (mon == 10 && d > 26)
  {
    if (dow == 0 && h >= 3)
    {
      setSummertime(false);
      return;
    } else if (dow > 0) {
      switch (d)
      {
        case 26:
          {
            if (dow -1 == 0)
            {
              //The day before was a Sunday
              setSummertime(false);
              return;
            }        
          }
          break;

        case 27:
          {
            for (int i=1; i<=2; i++)
            {
              if (dow -i == 0)
              {
                //Before there was a Sunday
                setSummertime(false);
                return;
              } 
            }
          }
          break;

        case 28:
          {
            for (int i=1; i<=3; i++)
            {
              if (dow -i == 0)
              {
                //Before there was a Sunday
                setSummertime(false);
                return;
              } 
            }
          }
          break;

        case 29:
          {
            for (int i=1; i<=4; i++)
            {
              if (dow -i == 0)
              {
                //Before there was a Sunday
                setSummertime(false);
                return;
              } 
            }
          }
          break;

        
        case 30:
          {
            for (int i=1; i<=5; i++)
            {
              if (dow -i == 0)
              {
                //Before there was a Sunday
                setSummertime(false);
                return;
              } 
            }
          }
          break;

        
        case 31:
          {
            for (int i=1; i<=6; i++)
            {
              if (dow -i == 0)
              {
                //Before there was a Sunday
                setSummertime(false);
                return;
              } 
            }
          }
          break;
      }        
    }
  }


  /*
   * Anyway lets do a check if we have the right routine: Suppose October 1 is a Sunday. That means the 25th is a 
   * Wednesday and the 29th a Sunday (the last and 5th Sunday), so the routine will indeed be activated on the 29th 
   * as all conditions are met. Suppose October starts on a Monday. That means there are only 4 Sundays and the last 
   * Sunday will fall on the 28th. Again, that is between 25 and 31 so the condition is met. Suppose October first 
   * falls on a Thursday, then the 25th will be a Sunday (the fourth Sunday) and the 31st will be a Saturday, so 
   * again the condition will be met for the last (and in this case 4th Sunday).
   * 
   * To start summertime/daylightsaving time on the last Sunday in March is mutatis mutandis the same.
   * March also has 31 days so the calculations are the same. This time though we check at 2 am and a 
   * reset DST flag and then set the clock to 3 am.
  */

  if (mon >= 4 && mon < 10)
  {
    setSummertime(true);
    return;
  } else if (mon == 3 && d < 25)
  {
    setSummertime(false);
    return;    
  } else if (dow == 0 && mon == 3 && d >= 25 && h >= 2)
  {
    setSummertime(true);
    return;
  } else if (mon == 3 && d > 25)
  {
    if (dow == 0 && h >= 2)
    {
      setSummertime(true);
      return;
    } else if (dow > 0) {
      switch (d)
      {
        case 26:
          {
            if (dow -1 == 0)
            {
              //The day before was a Sunday
              setSummertime(true);
              return;
            }        
          }
          break;

        case 27:
          {
            for (int i=1; i<=2; i++)
            {
              if (dow -i == 0)
              {
                //Before there was a Sunday
                setSummertime(true);
                return;
              } 
            }
          }
          break;

        case 28:
          {
            for (int i=1; i<=3; i++)
            {
              if (dow -i == 0)
              {
                //Before there was a Sunday
                setSummertime(true);
                return;
              } 
            }
          }
          break;

        case 29:
          {
            for (int i=1; i<=4; i++)
            {
              if (dow -i == 0)
              {
                //Before there was a Sunday
                setSummertime(true);
                return;
              } 
            }
          }
          break;
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

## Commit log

2021-10-06 Extending readme and initial documentation Adding pictures Adding first working arduino project Adding main case (without back lid)
    [Clock-MainCase_LED-Matrix-ESP8266_v1.stl]
2021-10-08 Fixing Markdown syntax, adding back lid and some related words
    [Clock-BackLid_LED-Matrix-ESP8266_v1.stl]
2021-10-25 Fixing summer/winter-time issue, adding more pictures
    [ntp.ino]
